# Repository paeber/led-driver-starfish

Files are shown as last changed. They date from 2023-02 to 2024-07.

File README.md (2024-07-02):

# LED Driver - Starfish
ESP32 based LED driver designed for use with ESPHome.

The pcb is designed with KiCad and has a ESP32-S3 with power and usb circuit. A total of four N-Channel FETs allow to switch 12V appliances (LED) upto 4.4A each. The four channels allow multiple LED strips or ones with RGBW etc.

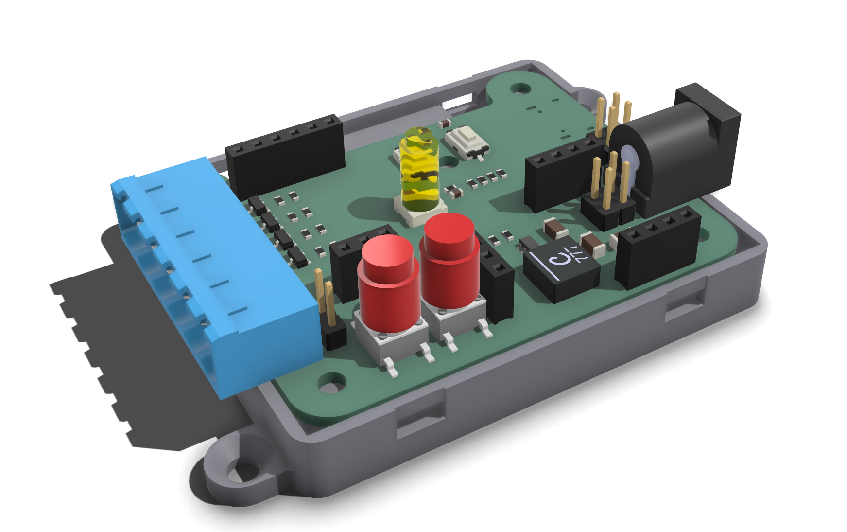
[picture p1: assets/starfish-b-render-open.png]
starfish-b-render
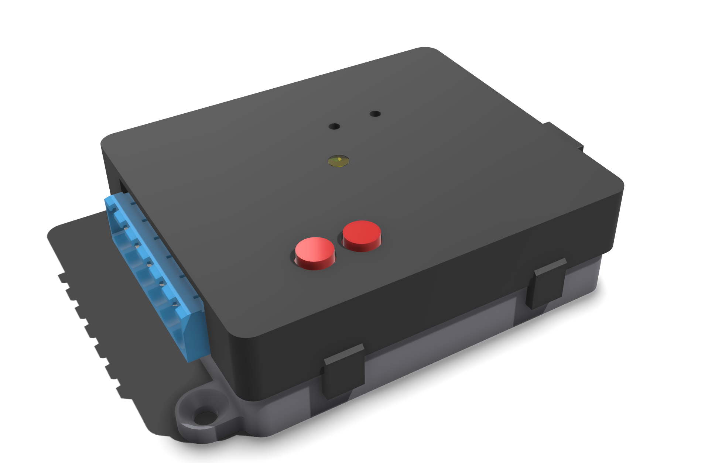
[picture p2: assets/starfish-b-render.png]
starfish-b-render


## Features

- ESP32-S3 for use with ESPHome

- 4 Open-Drain Channels for RGBW
- 2 Buttons for user input
- WS2812 LED
- Multiple headers for further peripherals (I2C,  3V3, 5V, GPIOs)
- 6V to 15V Input

## ESPHome Code

YAML configuration for ESPHome. Adapt as you need for your setup. Code is relevant for latest version (rev B).

### Base

```yaml
substitutions:
  dev_name: Kitchen

esphome:
  name: kitchen-starfish
  friendly_name: kitchen-starfish
  comment: ESP32 based LED driver for 12 V LED Strips

  on_boot:
    light.turn_on:
      id: status_led
      brightness: 20%
      green: 30%
      
esp32:
  variant: esp32s3
  board: esp32-s3-devkitc-1
  framework:
    type: arduino
```

### Internal LED

```yaml
light:
  - platform: esp32_rmt_led_strip
    id: status_led
    rgb_order: GRB
    pin: GPIO38
    num_leds: 1
    rmt_channel: 0
    chipset: ws2812
    name: "Status"
    internal: true
```

### PWM Output

```yaml
output:
  - platform: ledc
    id: output_component1
    pin: GPIO6
    frequency: 19531

  - platform: ledc
    id: output_component2
    pin: GPIO5
    frequency: 19531
```

### Dimmable Light

```yaml
light:
  - platform: monochromatic
    name: ${dev_name} Ceiling
    output: output_component1
```

### Buttons

```yaml
binary_sensor:
  - platform: gpio
    pin: 
      number: GPIO8
      inverted: True
    name: ${dev_name} BTN_1

  - platform: gpio
    pin: 
      number: GPIO11
      inverted: True
    name: ${dev_name} BTN_2
```

### I2C Header

```yaml
i2c:
  scl: GPIO9
  sda: GPIO10
```

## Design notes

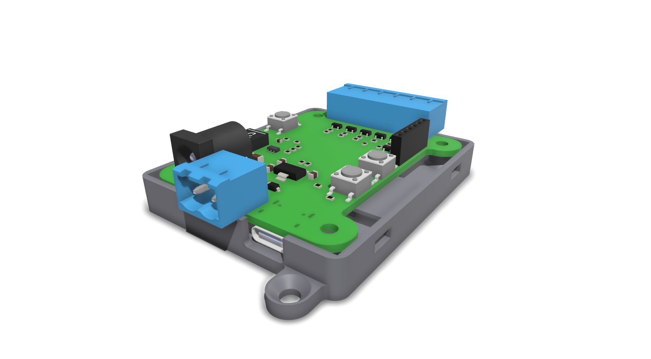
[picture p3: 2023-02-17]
assets/Starfish-Visual.png

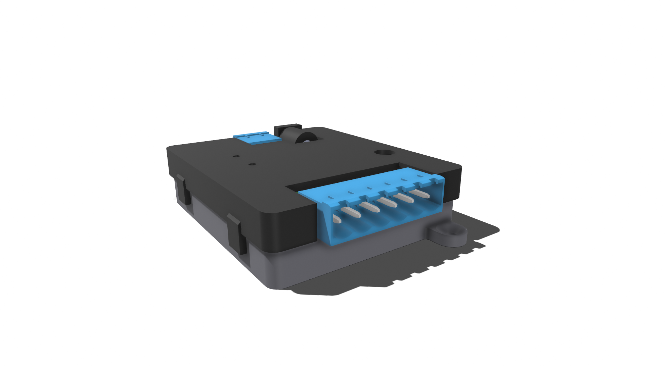
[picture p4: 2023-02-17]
assets/Starfish-Closed.png

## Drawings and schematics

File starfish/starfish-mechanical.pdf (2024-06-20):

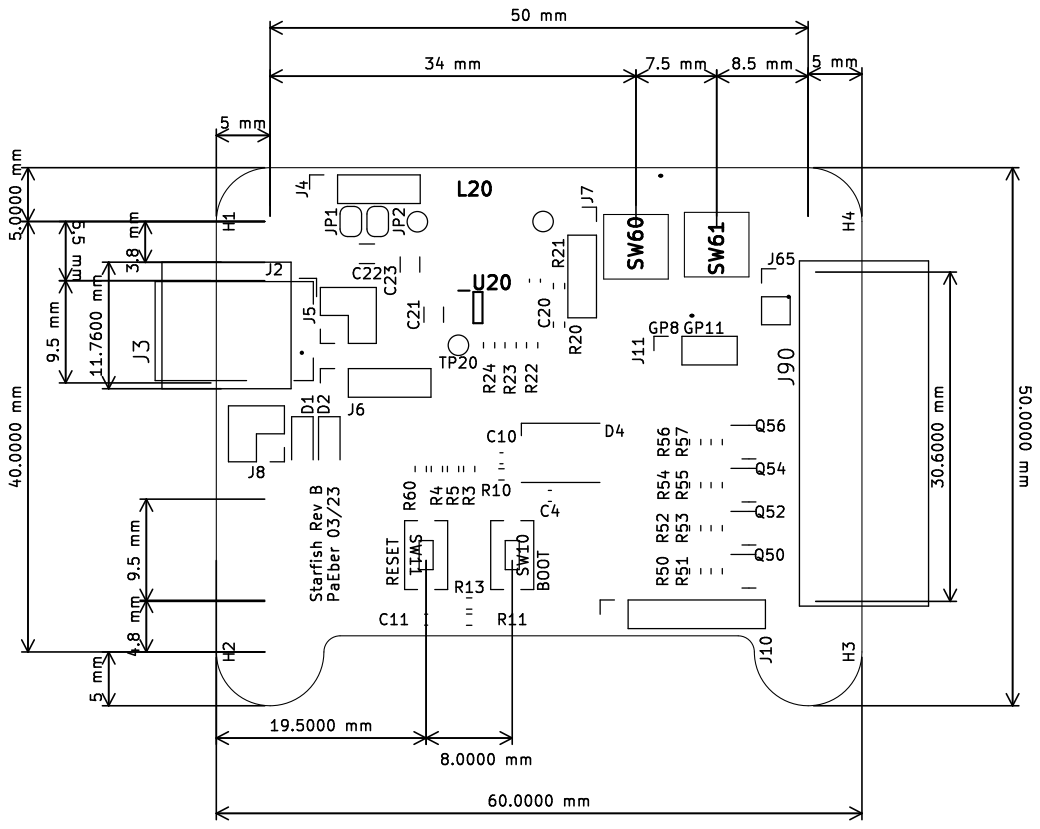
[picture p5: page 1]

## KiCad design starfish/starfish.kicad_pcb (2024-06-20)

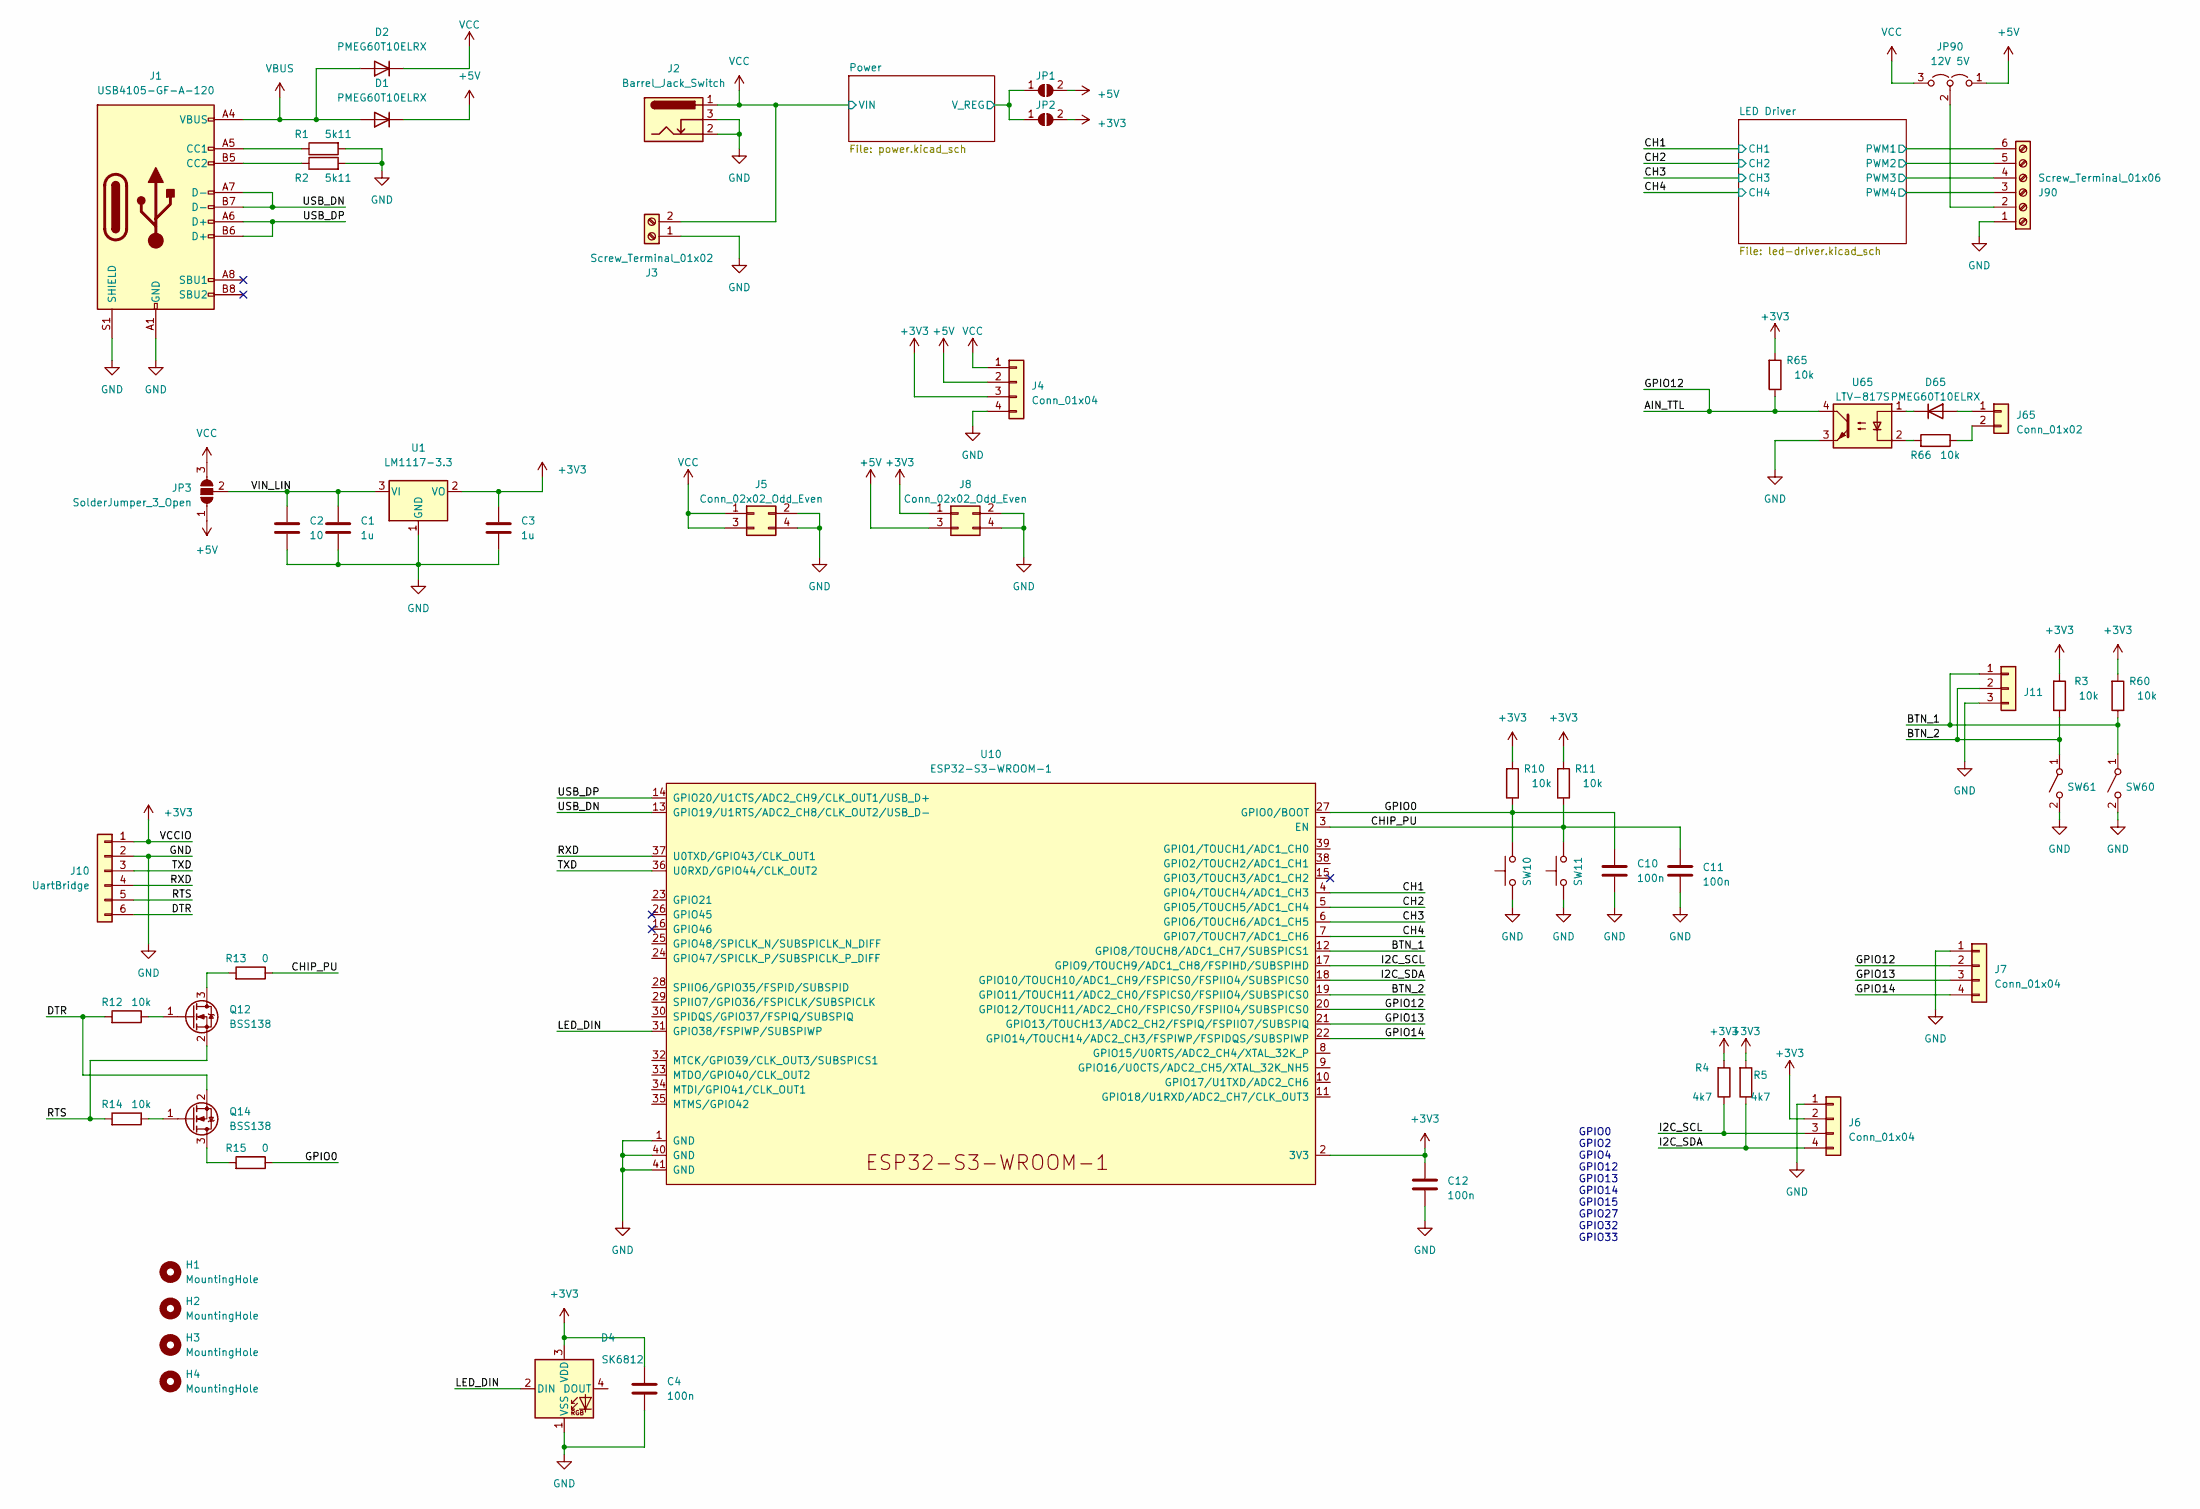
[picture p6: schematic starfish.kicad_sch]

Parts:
C1, C3: 1u; C_0805_2012Metric_Pad1.18x1.45mm_HandSolder
C2: 10; C_0805_2012Metric_Pad1.18x1.45mm_HandSolder
C4, C10, C11, C12: 100n; C_0603_1608Metric_Pad1.08x0.95mm_HandSolder; Mouser 581-06035C104KAT2A
D1, D2, D65: PMEG60T10ELRX; D_SOD-123; Mouser 771-PMEG60T10ELRX
D4: SK6812; LED_SK6812_PLCC4_5.0x5.0mm_P3.2mm
H1, H2, H3, H4: MountingHole; MountingHole_3.2mm_M3_DIN965_Pad_TopBottom
J1: USB4105-GF-A-120; USB_C_Receptacle_HRO_TYPE-C-31-M-12; Mouser 640-USB4105-GF-A-120
J2: Barrel_Jack_Switch; BarrelJack_Wuerth_6941xx301002; Mouser 992-CON-SOCJ-2155
J3: Screw_Terminal_01x02; CUI_TBP01R1-508-02BE; Mouser 490-TBP01R1-508-02BE
J4, J6, J7: Conn_01x04; PinSocket_1x04_P2.54mm_Vertical
J5, J8: Conn_02x02_Odd_Even; PinHeader_2x02_P2.54mm_Vertical
J10: UartBridge; PinSocket_1x06_P2.54mm_Vertical
J11: Conn_01x03; PinSocket_1x03_P2.54mm_Vertical
J65: Conn_01x02; PinHeader_1x02_P2.54mm_Vertical
J90: Screw_Terminal_01x06; CUI_TBP01R1-508-06BE; Mouser 490-TBP01R1-508-06BE
JP1, JP2: SolderJumper_2_Open; SolderJumper-2_P1.3mm_Open_RoundedPad1.0x1.5mm
JP3: SolderJumper_3_Open; SolderJumper-3_P1.3mm_Open_RoundedPad1.0x1.5mm
JP90: 12V 5V; SolderJumper-3_P1.3mm_Open_RoundedPad1.0x1.5mm_NumberLabels
Q12, Q14: BSS138; SOT-23
R1, R2: 5k11; R_0603_1608Metric_Pad0.98x0.95mm_HandSolder
R3, R10, R11, R12, R14, R60, R65, R66: 10k; R_0603_1608Metric_Pad0.98x0.95mm_HandSolder
R4, R5: 4k7; R_0603_1608Metric_Pad0.98x0.95mm_HandSolder
R13, R15: 0; R_0603_1608Metric_Pad0.98x0.95mm_HandSolder
SW10, SW11: PTS636SK25; SW_Tactile_SPST_NO_Straight_CK_PTS636Sx25SMTRLFS; Mouser 611-PTS636SK25SMTRLF
SW60, SW61: 1301.9315; 13019319; Mouser 693-1301.9315
U1: LM1117-3.3; SOT-223-3_TabPin2
U10: ESP32-S3-WROOM-1
U65: LTV-817S; SMDIP-4_W9.53mm

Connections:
+3V3: C3.1, C4.1, C12.1, D4.3 (VDD), J4.3, J6.2, J8.1, J10.1, JP2.2 (B), R3.2, R4.2, R5.2, R10.2, R11.2, R60.2, R65.2, U1.2 (VO), U10.2 (3V3)
+5V: D1.1 (K), J4.2, J8.3, JP1.2 (B), JP3.1 (A), JP90.1 (A)
/AIN_TTL: J7.2, R65.1, U10.20 (GPIO12/TOUCH11/ADC2_CH0/FSPICS0/FSPIIO4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), U65.4
/BTN_1: J11.1, R60.1, SW60.1 (A), U10.12 (GPIO8/TOUCH8/ADC1_CH7/SUBSPICS1)
/BTN_2: J11.2, R3.1, SW61.1 (A), U10.19 (GPIO11/TOUCH11/ADC2_CH0/FSPICS0/FSPIIO4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)
/CH1: U10.4 (GPIO4/TOUCH4/ADC1_CH3); also elsewhere on the board
/CH2: U10.5 (GPIO5/TOUCH5/ADC1_CH4); also elsewhere on the board
/CH3: U10.6 (GPIO6/TOUCH6/ADC1_CH5); also elsewhere on the board
/CH4: U10.7 (GPIO7/TOUCH7/ADC1_CH6); also elsewhere on the board
/CHIP_PU: C11.1, R11.1, R13.1, SW11.2, U10.3 (EN)
/DTR: J10.6, Q14.2 (S), R12.2
/GPIO0: C10.1, R10.1, R15.1, SW10.2, U10.27 (GPIO0/BOOT)
/GPIO13: J7.3, U10.21 (GPIO13/TOUCH13/ADC2_CH2/FSPIQ/FSPIIO7/S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)
/GPIO14: J7.4, U10.22 (GPIO14/TOUCH14/ADC2_CH3/FSPIWP/FSPIDQS/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)
/I2C_SCL: J6.3, R4.1, U10.17 (GPIO9/TOUCH9/ADC1_CH8/FSPIHD/SUBSPIHD)
/I2C_SDA: J6.4, R5.1, U10.18 (GPIO10/TOUCH10/ADC1_CH9/FSPICS0/FSPIIO4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)
/LED Driver/PWM1: J90.6; also elsewhere on the board
/LED Driver/PWM2: J90.5; also elsewhere on the board
/LED Driver/PWM3: J90.4; also elsewhere on the board
/LED Driver/PWM4: J90.3; also elsewhere on the board
/LED_DIN: D4.2 (DIN), U10.31 (GPIO38/FSPIWP/SUBSPIWP)
/Power/V_REG: JP1.1 (A), JP2.1 (A); also elsewhere on the board
/RTS: J10.5, Q12.2 (S), R14.2
/RXD: J10.4, U10.37 (U0TXD/GPIO43/CLK_OUT1)
/TXD: J10.3, U10.36 (U0RXD/GPIO44/CLK_OUT2)
/USB_DN: J1.A7 (D-), J1.B7 (D-), U10.13 (GPIO19/U1RTS/ADC2_CH8/CLK_OUT2/USB_D-)
/USB_DP: J1.A6 (D+), J1.B6 (D+), U10.14 (GPIO20/U1CTS/ADC2_CH9/CLK_OUT1/USB_D+)
/VIN_LIN: C1.1, C2.1, JP3.2 (C), U1.3 (VI)
GND: C1.2, C2.2, C3.2, C4.2, C10.2, C11.2, C12.2, D4.1 (VSS), J1.A1 (GND), J1.A12 (GND), J1.B1 (GND), J1.B12 (GND), J1.S1 (SHIELD), J2.2, J2.3, J3.1, J4.4, J5.2, J5.4, J6.1, J7.1, J8.2, J8.4, J10.2, J11.3, J90.1, R1.2, R2.2, SW10.1, SW11.1, SW60.2 (B), SW61.2 (B), U1.1 (GND), U10.1 (GND), U10.40 (GND), U10.41 (GND), U65.3; also elsewhere on the board
unnamed: D65.2 (A), J65.1
unnamed: D65.1 (K), U65.1
unnamed: J1.A5 (CC1), R1.1
unnamed: J1.B5 (CC2), R2.1
unnamed: J65.2, R66.1
unnamed: J90.2, JP90.2 (C)
unnamed: Q12.3 (D), R13.2
unnamed: Q12.1 (G), R12.1
unnamed: Q14.3 (D), R15.2
unnamed: Q14.1 (G), R14.1
unnamed: R66.2, U65.2
VBUS: D1.2 (A), D2.2 (A), J1.A4 (VBUS), J1.A9 (VBUS), J1.B4 (VBUS), J1.B9 (VBUS)
VCC: D2.1 (K), J2.1, J3.2, J4.1, J5.1, J5.3, JP3.3 (B), JP90.3 (B); also elsewhere on the board

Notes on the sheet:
GPIO0 GPIO2 GPIO4 GPIO12 GPIO13 GPIO14 GPIO15 GPIO27 GPIO32 GPIO33

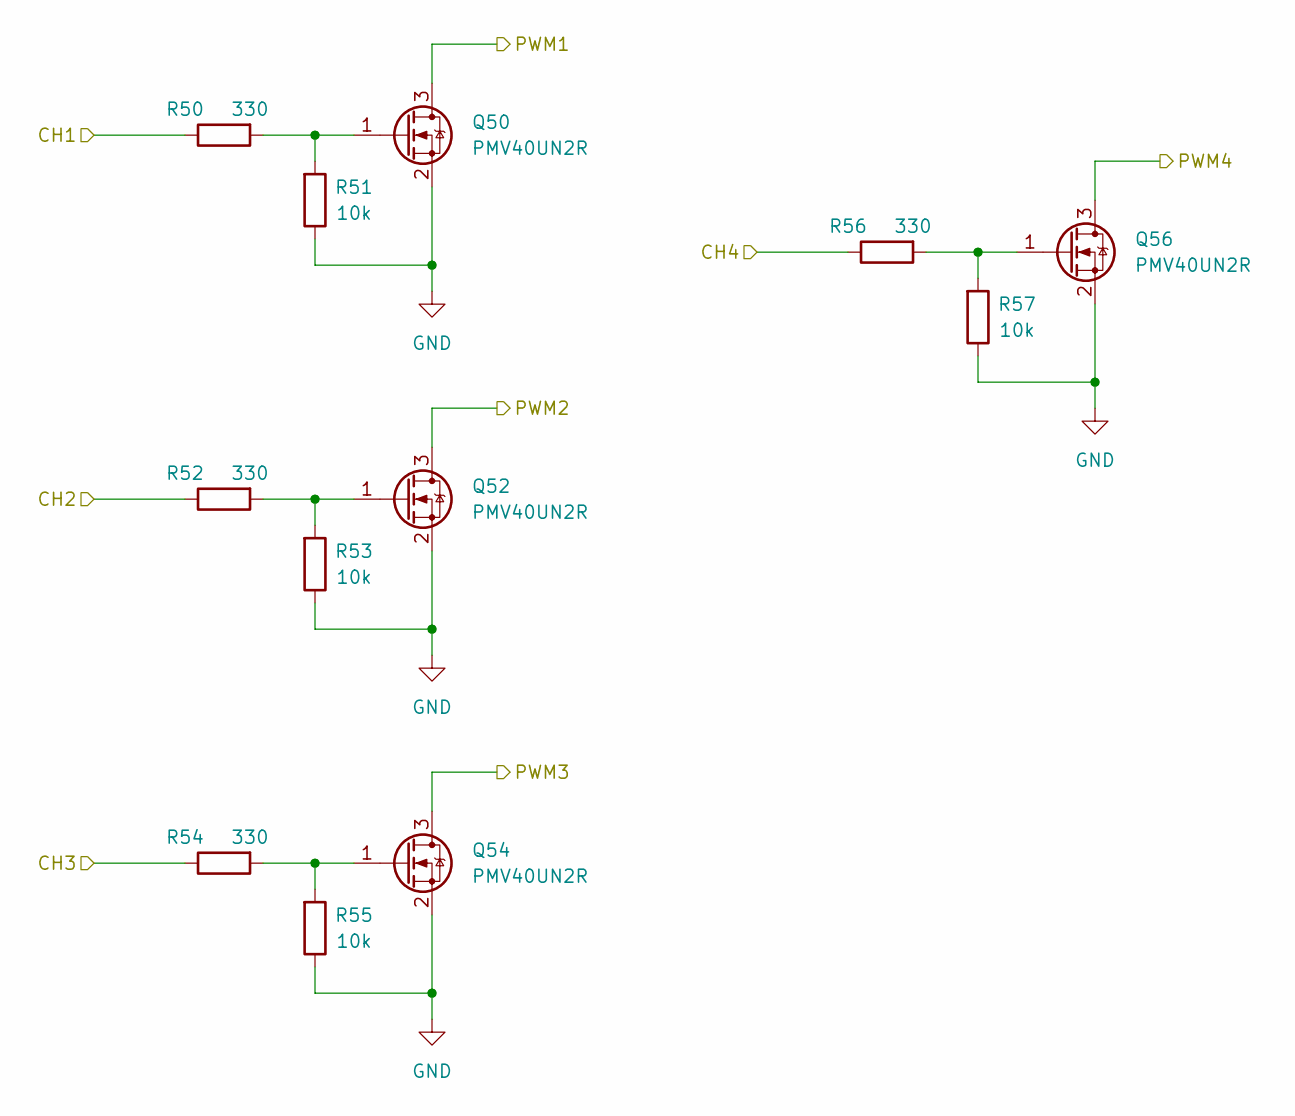
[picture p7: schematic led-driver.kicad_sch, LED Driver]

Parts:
Q50, Q52, Q54, Q56: PMV40UN2R; SOT-23; LCSC C130869
R50, R52, R54, R56: 330; R_0603_1608Metric_Pad0.98x0.95mm_HandSolder
R51, R53, R55, R57: 10k; R_0603_1608Metric_Pad0.98x0.95mm_HandSolder

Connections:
/CH1: R50.1; also elsewhere on the board
/CH2: R52.1; also elsewhere on the board
/CH3: R54.1; also elsewhere on the board
/CH4: R56.1; also elsewhere on the board
/LED Driver/PWM1: Q50.3 (D); also elsewhere on the board
/LED Driver/PWM2: Q52.3 (D); also elsewhere on the board
/LED Driver/PWM3: Q54.3 (D); also elsewhere on the board
/LED Driver/PWM4: Q56.3 (D); also elsewhere on the board
GND: Q50.2 (S), Q52.2 (S), Q54.2 (S), Q56.2 (S), R51.1, R53.1, R55.1, R57.1; also elsewhere on the board
unnamed: Q50.1 (G), R50.2, R51.2
unnamed: Q52.1 (G), R52.2, R53.2
unnamed: Q54.1 (G), R54.2, R55.2
unnamed: Q56.1 (G), R56.2, R57.2

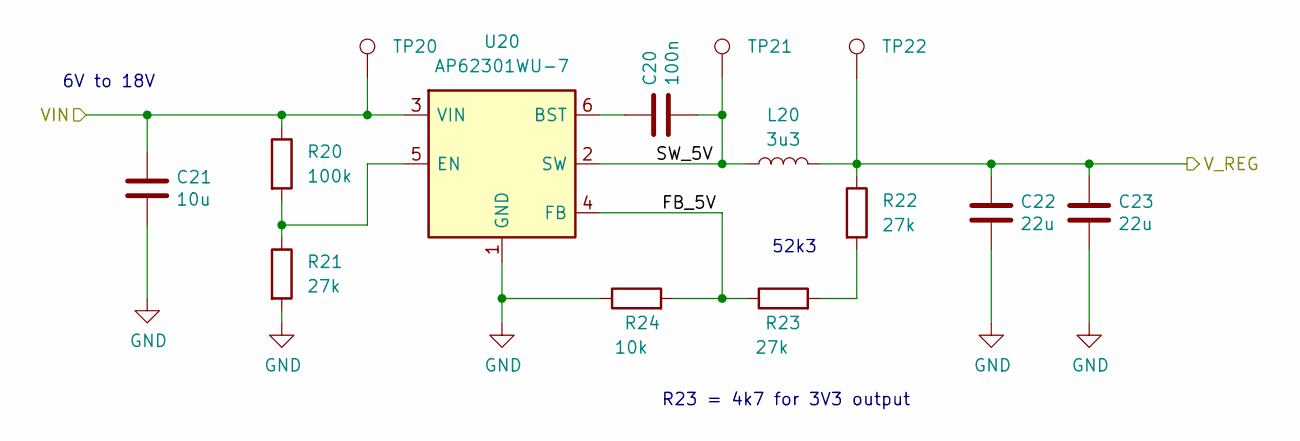
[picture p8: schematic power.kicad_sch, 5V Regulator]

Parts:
C20: 100n; C_0603_1608Metric_Pad1.08x0.95mm_HandSolder; Mouser 581-06035C104KAT2A
C21: 10u; C_1206_3216Metric; Mouser 581-1206DD106MAT2A
C22, C23: 22u; C_1206_3216Metric; Mouser 581-1206YD226MAT2A
L20: 3u3; XAL6030182MEB-HandSolder; Manufacturer_Part_Number XAL6030-332MEC; Mouser 994-XAL6030-332MEC
R20: 100k; R_0603_1608Metric_Pad0.98x0.95mm_HandSolder
R21, R22, R23: 27k; R_0603_1608Metric_Pad0.98x0.95mm_HandSolder
R24: 10k; R_0603_1608Metric_Pad0.98x0.95mm_HandSolder
TP20, TP21, TP22: TestPoint; TestPoint_Pad_D1.5mm
U20: AP62301WU-7; TSOT-26; Manufacturer_Part_Number AP62301WU-7; Mouser 621-AP62301WU-7

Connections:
/Power/FB_5V: R23.1, R24.2, U20.4 (FB)
/Power/SW_5V: C20.2, L20.1, TP21.1, U20.2 (SW)
/Power/V_REG: C22.1, C23.1, L20.2, R22.1, TP22.1; also elsewhere on the board
GND: C21.2, C22.2, C23.2, R21.2, R24.1, U20.1 (GND); also elsewhere on the board
unnamed: R22.2, R23.2
unnamed: C20.1, U20.6 (BST)
unnamed: R20.2, R21.1, U20.5 (EN)
VCC: C21.1, R20.1, TP20.1, U20.3 (VIN); also elsewhere on the board

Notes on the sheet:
52k3
R23 = 4k7 for 3V3 output
6V to 18V

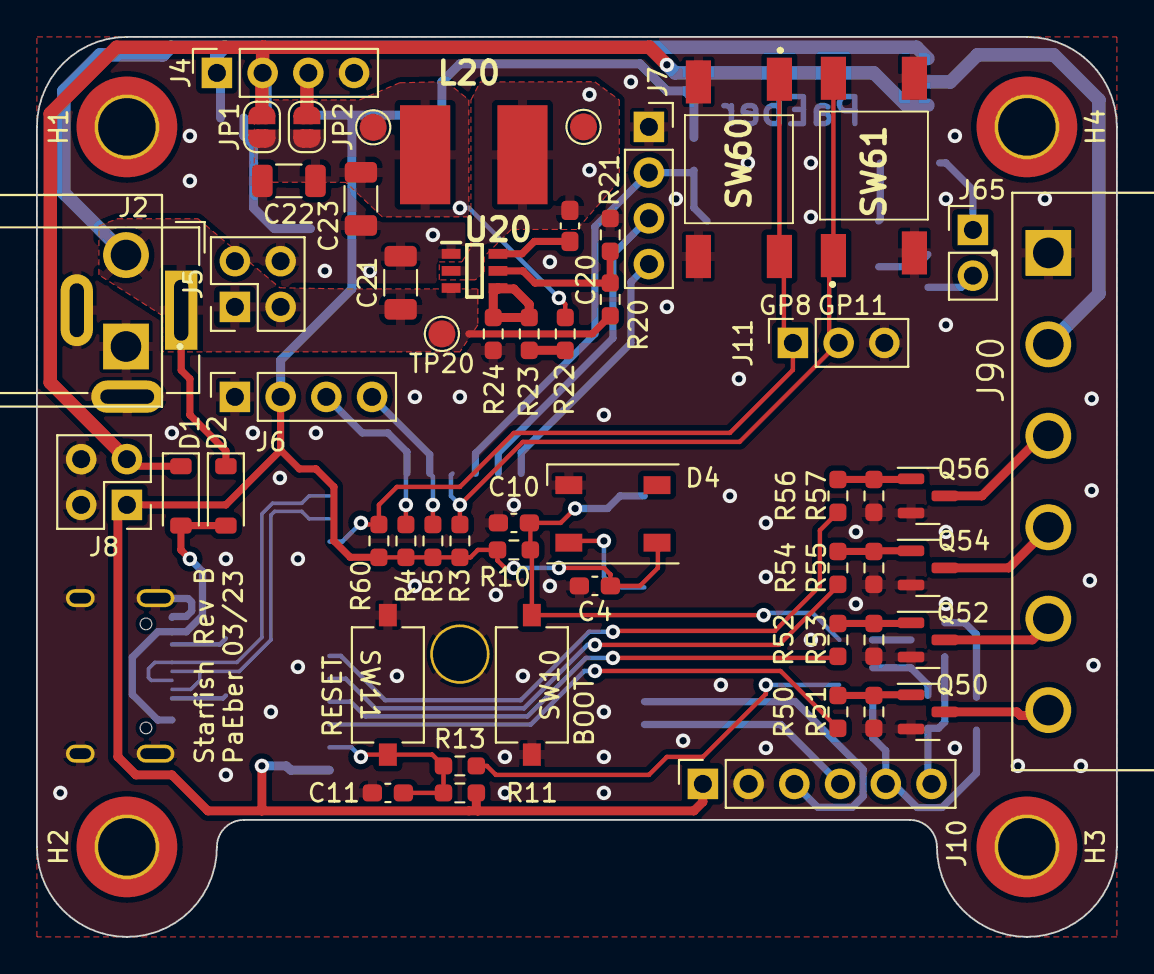
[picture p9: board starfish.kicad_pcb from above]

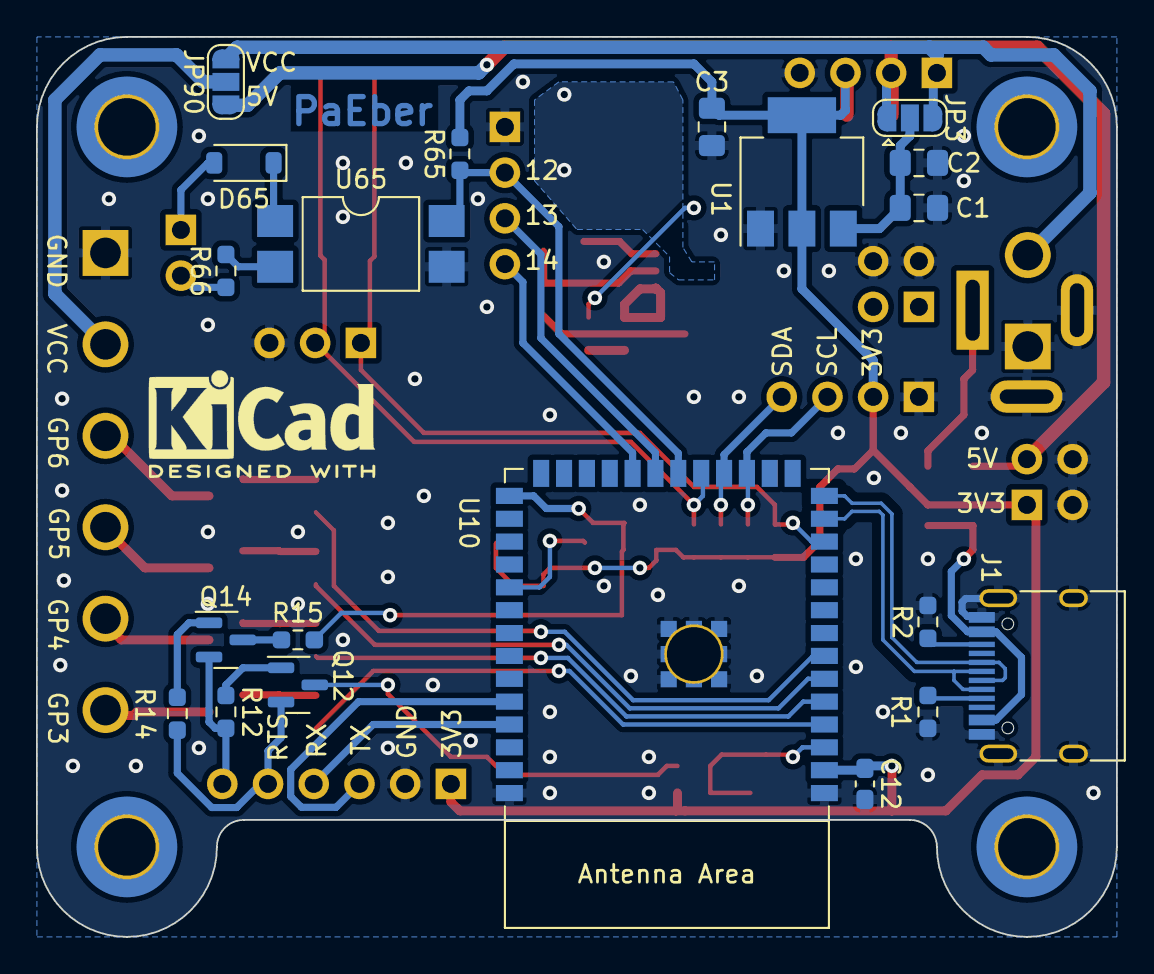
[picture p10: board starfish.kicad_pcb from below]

Board: 2 copper layers, 60.0 x 50.0 mm, 80 parts (20 on the bottom side), 51 nets.

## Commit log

2023-02-17 Add hardware design to github
    [led-driver.kicad_sch, power.kicad_sch, starfish.kicad_pcb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]
2023-03-06 Start rev b
    [led-driver.kicad_sch, power.kicad_sch, starfish.kicad_pcb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]
2023-03-07 Add some components
    [starfish.kicad_pcb, starfish.kicad_sch]
2023-03-08 Power progress
    [starfish.kicad_pcb, starfish.kicad_sch]
2023-03-09 Rev b progress
    [starfish.kicad_pcb, starfish.kicad_sch]
2023-03-11 Layout progress
    [power.kicad_sch, starfish.kicad_pcb, starfish.kicad_sch]
2023-03-13 RevB first gerber export
    [starfish.kicad_pcb, starfish.kicad_sch]
2023-06-15 rev B pcb complete
    [starfish.kicad_pcb]
2024-06-19 Update mechanical
    [starfish.kicad_pcb]
